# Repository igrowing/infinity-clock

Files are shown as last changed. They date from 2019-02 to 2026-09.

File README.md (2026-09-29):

# Infinity Mirror Clock

This repo follows and inspired by http://barkengmad.com/rise-and-shine-led-clock/

Original Morgan Barke's video:
[See the magic](https://youtu.be/YErWfe0aTiQ "Yoohoo!")

I like the original inifinity clock after reviewing dosen (or even more) similar devices. I appreciate Morgan's creativity and generosity for making his project public. Sharing is caring, and I'm giving back :)

This project fixes few issues in original clock and improves usability, user experience, and build ease.

[The clock demo in all modes (1 min 18 sec)](https://www.youtube.com/watch?v=9rUNe92n67c)

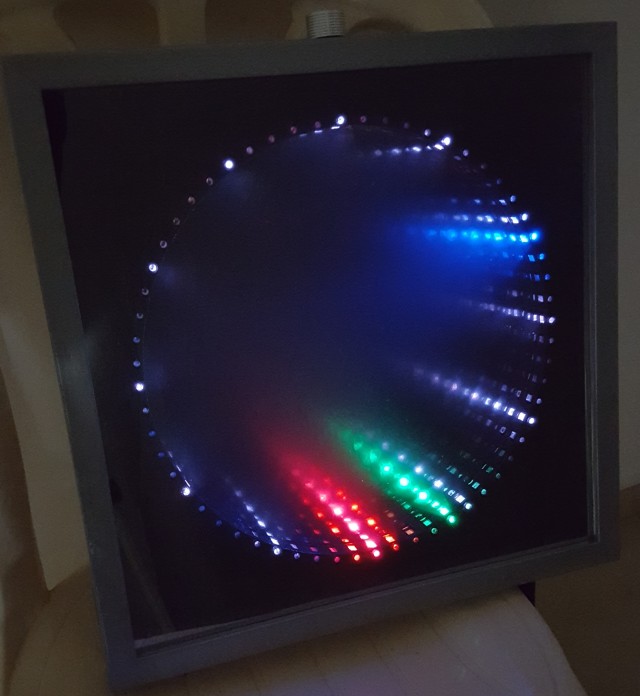
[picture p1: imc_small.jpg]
Infiniti mirror clock


# Features
- 8 modes of _clock_ display.
- 3 modes of _alarm_ display.
- Minute discrete timer.
- Demo mode.
- Buzzer.
- Power independent time count and settings store.
- WOW effect :)

# Usage
[See the PDF chart.](Infinity%20mirror%20clock%20user%20guide.pdf)

For fans of video guides:
- [Choosing Display mode of clock](https://www.youtube.com/watch?v=vU_UOzZHfpM)
- [Setting time and upright position](https://www.youtube.com/watch?v=-KVNCHQzmkM)
- [Alarm usage](https://www.youtube.com/watch?v=D5s8VyNlAFA)
- [Timer usage](https://www.youtube.com/watch?v=lTOYV0bmhKc)
- [Jump to demo mode and back to clock](https://www.youtube.com/watch?v=sZ3GmazdSDI)
- [Full user guide in one video](https://www.youtube.com/watch?v=MvB9e6Ny7ps)

# Changes vs. original clock
- Clock can be rotated by 90 degrees. This is useful for displaying the clock with the knob on the top (like traditional stopwatch) or on the right side (like tratitional watch).
- Use RTC NVRAM instead of EEPROM: this saves EEPROM wear out.
- Added rainbow to demo, endless demo, exit from demo by click.
- Move rotary button from A3 to D4: this helps ease of assembly.
- Refactor menu button work. Less code, easy readable.
- Keep clock mode and restore it after power failure.
- Refactor and make stable the rotary encoder.
- Breathing clock is more distinctive.
- Buzzer in Alarm and Timer modes.
- Remove excessive Serial prints.
- New Starry night clock mode.
- About 25% less code lines.
- Numerous bugs fixed.

# Build/compile
## Software
Original clock comes with libraries in archive. The libraries are outdated. Install in your Arduino/Platformio environment following libraries _before_ compiling:
- FastLED v3.2.1 and up
- Bounce2
- RTCLib
- Encoder of Paul Stoffregen
- EasyBuzzer

Likely, following libs are preinstalled by default:
- Wire

> Important: For some reason, the PlatformIO couldn't pick the EasyBuzzer. I guess this is related to [known bug of PlatformIO](https://community.platformio.org/t/platformio-home-page-cant-open/2768). Since numerous attempts to fix it failed, I switched to [command line control of libraries and boards](https://docs.platformio.org/en/latest/userguide/lib/index.html). So far it worked well, except the EasyBuzzer. Therefore, I added it to this repo: it will be easier to compile the entire project.

## Mechanics
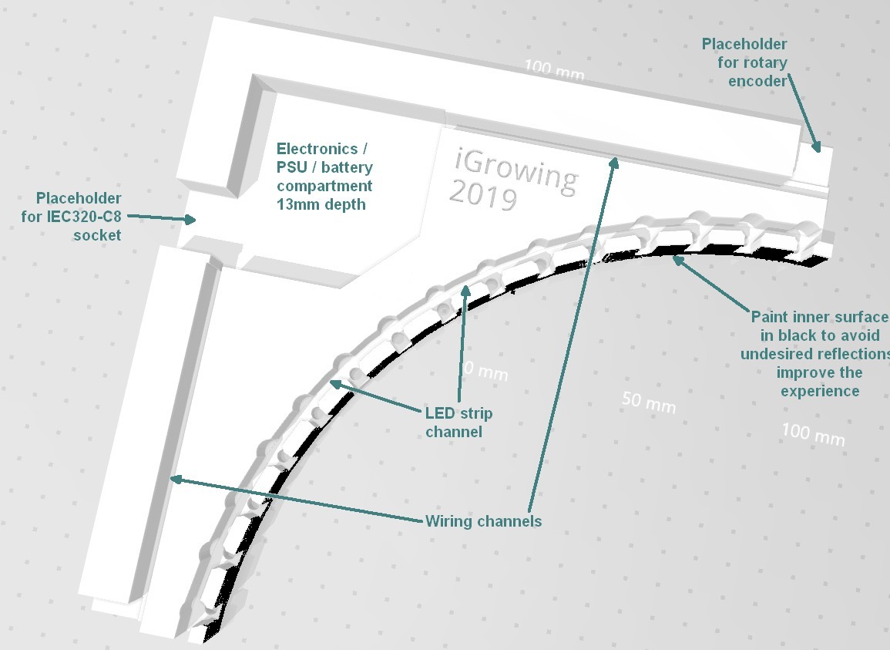
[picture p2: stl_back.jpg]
Back side of 3D model


Beside electronic components following material is needed:
- Knob for rotary encoder. 6mm inner diameter, the rest is on your taste. From 1.5 to 18 USD on eBay.
- Base plate made of layered wood or plastic for the back, 4-6mm thick, 38x38cm.
- PMMA or polycarbonate sheet for the front, 2.5-3mm thick, 38x38cm.
- Semi-transparent mirror, found on Amazon as "One Way Window Film". 
- Non-transparent mirror, found on Amazon.
- Frame on your taste from local painting shop.
- Wood or plastic for 3D model CNC milling. 16mm thick, 210x210mm (will be milled smaller). For CNC machine take 2-flute 20mm CEL carbide milling bits of 1/8".
or
- PETG or ABS filament for 3D printing, white color. PLA is good enough too, however, it's weak and thin part might break during handling/assembly.

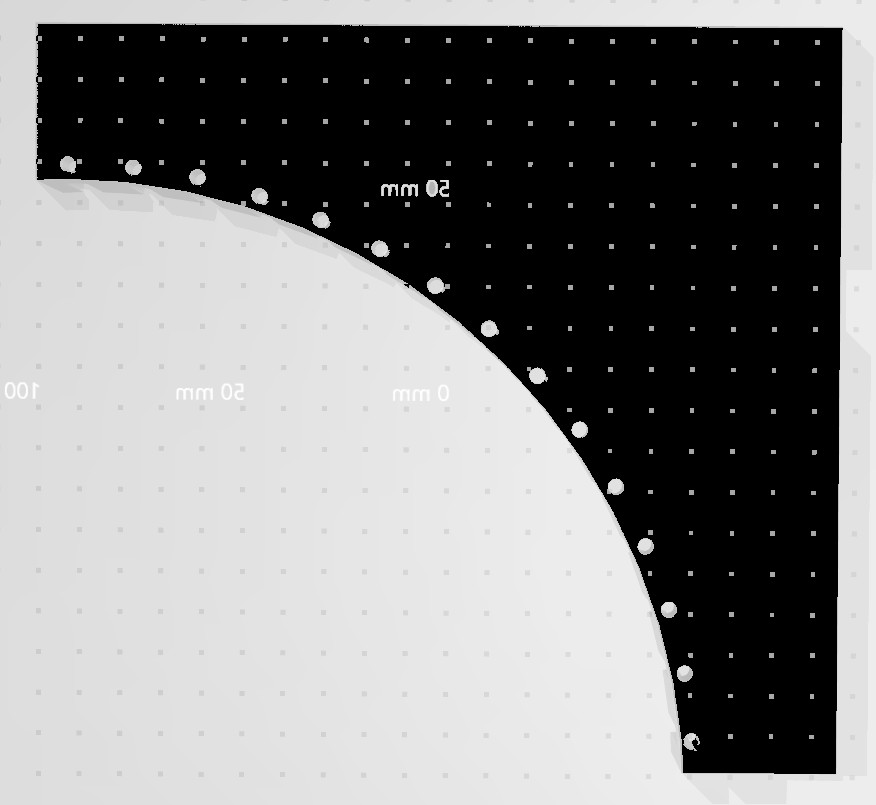
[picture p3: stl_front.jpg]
Front side of 3D model


It's hard to find large enough 3D printing service or CNC milling service. So I split the clock to 4 equal parts. Connect them side to side. Insert all electronics/wires in the channels. Place the back base with non-transparent mirror on all 4 parts connected. And screw all together.

Remember to paint the front side of the 3D model and inner ring with black. This stops unwanted reflections and improves the user experience (WOW effect). In the current STL model the light slots are high. This makes less distinguished mirror effect. Connecting free side of pins with 4 mm strip of black duct tape makes light windows, not channels and improves the UX.

## Electronics
The clock consumes about 1.5A @ 5V in worst case (white demo). Therefore, usual 2A USB charger is enough to power it up.

Per spare compartments: normally 1 compartment is populated with arduino electronics and the other one with PSU. In theory, 3 compartments can be used for 14400 Li-Ion or AAA Ni-MH batteries. Batteries might provide backup power up to 20 hours. I run my clock from AC mains.

Alternatives for power supply:
- Use rechargeable batteries.
- Use regular USB charger (2A or more).
- Hide the USB charger electonics in sepatate compartment and use IEC320-C8 socket for AC mains.

Lithium battery in RTC should be replaced once in few years. Rarely enough to make easy access to the electronics.

As LED strip, it's 1m 60 of WS8212B LEDs used. Any buzzer from old PC or Tablet or small loudspeaker is good.

# TODO
- Move alarm to RTC. This allows daily alarm.
- Buzzer sound isn't nice, kinda quack. Improve.
- Add PCB... (really?)

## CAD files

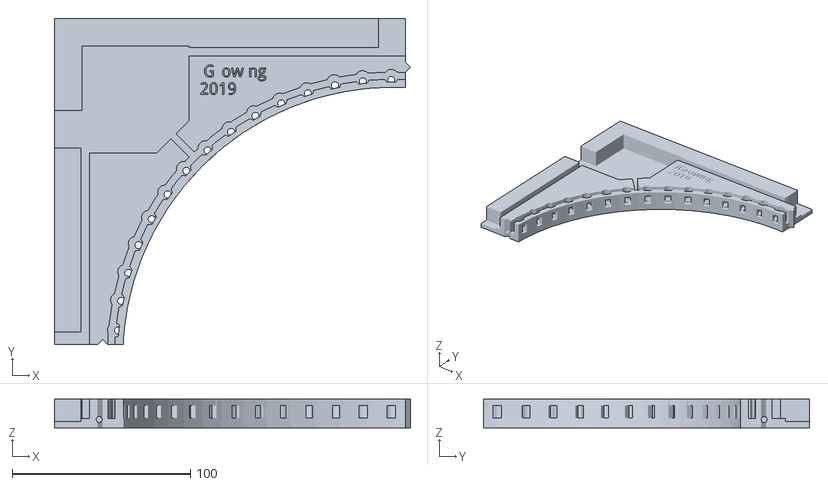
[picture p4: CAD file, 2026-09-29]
quarter clock wide opening.stl
199.8 x 183.0 x 16.0

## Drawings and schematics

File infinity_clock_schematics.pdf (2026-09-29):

A

A

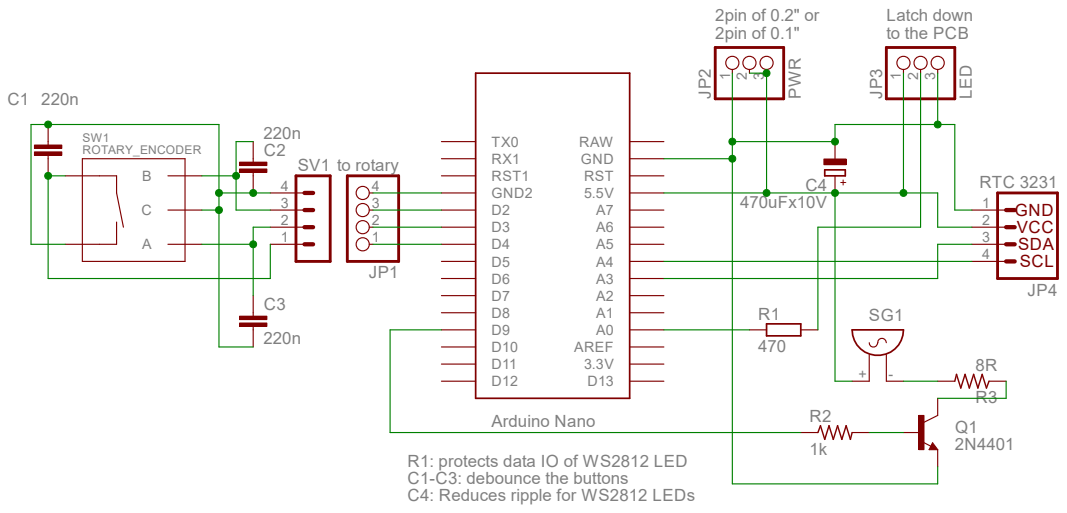
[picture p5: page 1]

ROTARY_ENCODER

R1: protects data IO of WS2812 LED
C1-C3: debounce the buttons
C4: Reduces ripple for WS2812 LEDs

29-Sep-26 17:00:17 C:\Users\igory\OneDrive\Documents\eagle\eagle\infinity mirror clock\clock.sch (Sheet: 1/1)

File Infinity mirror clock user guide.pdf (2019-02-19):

## Change mode +/-

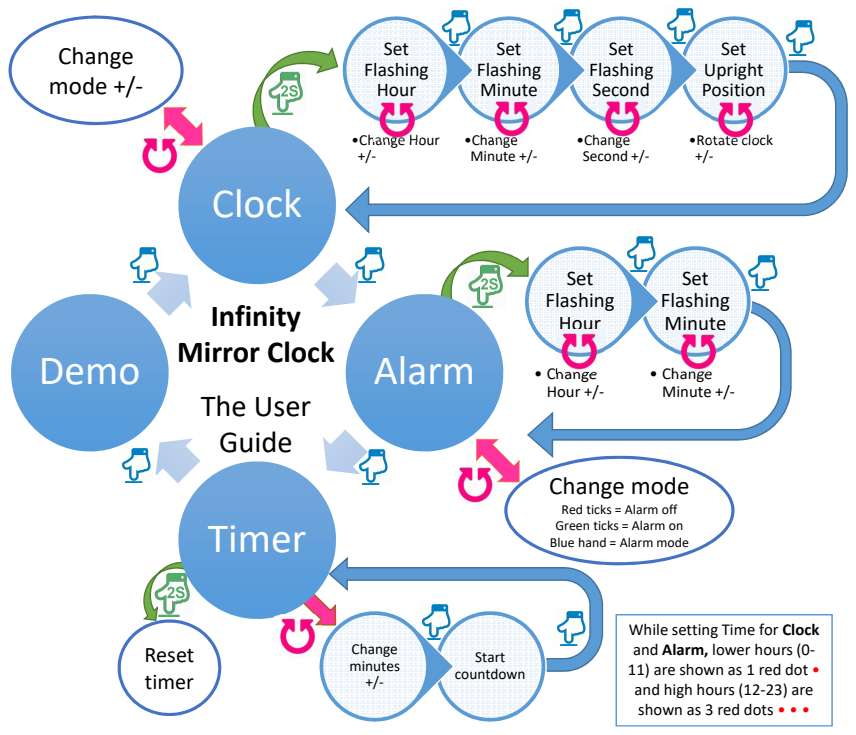
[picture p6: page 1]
Clock; Alarm; Timer; Demo; Set Upright Position; •Rotate clock +/-; Set Flashing Second; •Change Second +/-; Set Flashing Minute; •Change Minute +/-; Set Flashing Hour; •Change Hour +/-; • Change Minute +/-; • Change Hour +/-; Start countdown; Change minutes +/-; Change mode; Reset timer; Infinity Mirror Clock; The User Guide

Red ticks = Alarm off
Green ticks = Alarm on
Blue hand = Alarm mode

While setting Time for Clock
and Alarm, lower hours (0-
11) are shown as 1 red dot •
and high hours (12-23) are
shown as 3 red dots • • •

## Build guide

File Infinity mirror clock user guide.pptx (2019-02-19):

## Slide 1

Change mode +/-

Set Flashing Hour

  - Change Hour +/-

Set Flashing Minute

  - Change Minute +/-

Set Flashing Second

  - Change Second +/-

Set Upright Position

  - Rotate clock +/-

Set Flashing Hour

  - Change Hour +/-

Set Flashing Minute

  - Change Minute +/-

Change mode
Red ticks = Alarm off
Green ticks = Alarm on
Blue hand = Alarm mode

While setting Time for Clock and Alarm, lower hours (0-11) are shown as 1 red dot • and high hours (12-23) are shown as 3 red dots • • •

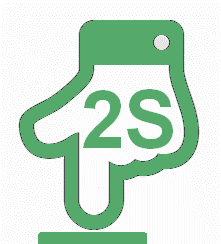
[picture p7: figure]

Clock

Demo

Alarm

Timer

Infinity Mirror Clock
The User Guide

Reset timer

Change minutes +/-

Start countdown

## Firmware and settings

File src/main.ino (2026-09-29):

/***********************************************************
 * Inspired by http://barkengmad.com/rise-and-shine-led-clock/
 * and based Morgan Barke's code.
 *
 * Modded by iGrowing 2019.
 * https://github.com/igrowing/infinity-clock
 *
 * Layout of the code:
 *   main.ino    setup, loop and the glue between the buttons, the menu and the hardware
 *   leds        the LED ring and the drawing primitives
 *   faces       the different ways of showing the time
 *   screens     setting screens, timer, demo and the alarm effects
 *   buzzer      the sound
 *   settings    what is kept in the NVRAM of the RTC
 *   lib/clock_logic   pure logic, unit-tested on the PC: menu state machine, beep timing, alarm decision, ...
 ***********************************************************/

//Add the following libraries to the respective folder for you operating system. See http://arduino.cc/en/Guide/Environment
#include <FastLED.h> // FastSPI Library version 3.1.X from https://github.com/FastLED/FastLED. Version 3.0.X has a bug: all LEDs are green by default.
#include <Wire.h> //This is to communicate via I2C. On arduino Uno & Nano use pins A4 for SDA (yellow/orange) and A5 for SCL (green). For other boards ee http://arduino.cc/en/Reference/Wire
#include <RTClib.h>           // Include the RTClib library to enable communication with the real time clock.
#include <Bounce2.h>          // Include the Bounce library for de-bouncing issues with push buttons.
#include <Encoder.h>          // Include the Encoder library to read the out puts of the rotary encoders
#include <menu_machine.h>     // Menu state machine, unit-tested on PC
#include "config.h"
#include "log.h"
#include "rtc.h"
#include "leds.h"
#include "faces.h"
#include "screens.h"
#include "buzzer.h"
#include "settings.h"

RTC_DS1307 RTC;     // Establishes the chipset of the Real Time Clock
MenuModel menu;     // Everything the user can change: state, modes, alarm, timer
Encoder rotary1(PIN2, PIN3); // Setting up the Rotary Encoder
Bounce menuBouncer = Bounce(PIN_MENU,30); // Instantiate a Bounce object with a 30 millisecond debounce time for the menu button
unsigned long lastRotary = 0;

// Silence the buzzer, forget any ringing state and go back to the clock.
void clearBuzzer() {
  buzzerReset();
  menu.state = STATE_CLOCK;
  menu.countDown = false;
}

void printDateTime() {
  DateTime now = RTC.now();
  // Sanity check for stored time
  if (now.hour() > 23 || now.minute() > 59 || now.second() > 59 || now.month() > 12 || now.day() > 31) {
    RTC.adjust(DateTime(2018, 1, 1, 1, 1, 1));
    now = RTC.now();
    Serial.println(F("Fixed date and time."));
  }
  printValue(F("Hour time is... "), now.hour());
  printValue(F("Min time is... "), now.minute());
  printValue(F("Sec time is... "), now.second());
  printValue(F("Year is... "), now.year());
  printValue(F("Month is... "), now.month());
  printValue(F("Day is... "), now.day());
}

void setup() {
  // Attach after enabling the pull-up: the global Bounce object was constructed before this and latched a floating pin level.
  menuBouncer.attach(PIN_MENU, INPUT_PULLUP);  // Uses the internal 20k pull up resistor. Pre Arduino_v.1.0.1 need to be "digitalWrite(PIN_MENU,HIGH);pinMode(PIN_MENU,INPUT);"

  // Start LEDs
  LEDS.addLeds<WS2812B, PIN_LEDS, GRB>(leds, NUM_LEDS); // Structure of the LED data. I have changed to from rgb to grb, as using an alternative LED strip. Test & change these if you're getting different colours.

  // Start RTC
  Wire.begin(); // Starts the Wire library allows I2C communication to the Real Time Clock
  RTC.begin(); // Starts communications to the RTC

  Serial.begin(9600); // Starts the serial communications

  // Load any saved setting since power off, such as mode & alarm time
  loadSettings(menu);
  setLedOffset(menu.ledOffset);
  rotary1.write(0);  // Set non-interrupt mode to rotary
  menu.state = STATE_CLOCK;

  printSettings(menu);
  printDateTime();

  buzzerBegin();
}

// Carry out what the menu state machine asked for.
void applyMenuEffects(const MenuEffects& fx) {
  if (fx.blinkDisplay) {  // blink display while button is pressed to indicate "entered adjust mode"
    clearLEDs();
    LEDS.show();
    delay(100);
  }
  if (fx.setTime) {
    RTC.adjust(DateTime(fx.newTime.year, fx.newTime.month, fx.newTime.day, fx.newTime.hour, fx.newTime.minute, fx.newTime.second));
  }
  if (fx.clearBuzzer) clearBuzzer();
  if (fx.stopBuzzer) buzzerStop();
  if (fx.resetSecTimer) restartSecondTimer();
  if (fx.resetSweep) resetSweep();
  if (fx.startDemo) startDemo();
  if (fx.saveLedOffset) setLedOffset(menu.ledOffset);
  saveSettings(menu, fx);
  if (fx.printDateTime) printDateTime();
  if (fx.waitAfterAlarmCancel) delay(300);  // let time for the button to be released
}

// Feed the state of the button into the menu state machine and act on the result.
void buttonCheck(Bounce& button, DateTime now) {
  MenuInput in = {};
  in.pressed = !button.read();
  in.heldMs = in.pressed ? button.currentDuration() : 0;
  in.released = button.rose();
  in.clockModeCount = clockFaceCount();
  in.now = toNowInfo(now);

  State stateBefore = menu.state;
  MenuEffects fx = menuStep(menu, in);
  applyMenuEffects(fx);

  if (stateBefore == STATE_ALARM && !fx.waitAfterAlarmCancel) {
    printValue(F("alarmSet is "), menu.alarmSet);
    printValue(F("alarmMode is "), menu.alarmMode);
  }
  if (!fx.waitAfterAlarmCancel) {
    printValue(F("Mode is "), menu.clockMode);
    printValue(F("State is "), (int)menu.state);
  }
}

void loop() {
  DateTime now = RTC.now(); // Fetches the time from RTC
  if (buzzerUpdate()) clearBuzzer();  // The timer beeps are over

  // Check for any button presses and action accordingly
  bool buttonChanged = menuBouncer.update();  // Update the debouncer for the menu button
  int rotaryPos = rotary1.read(); // Checks the rotary position
  if (rotaryPos != 0) {
    if (millis() - lastRotary >= ROTARY_SET_TIME_MS) {
      menu.rotaryMove = (rotaryPos < 0)?-1:1;  // Limit moves to single step.
      lastRotary = millis();
    }
    rotary1.write(0);  // Reset position, whether the move was valid or not.
  }
  if (buttonChanged || menu.rotaryMove != 0 || menu.countTime) {buttonCheck(menuBouncer, now);}

  clearLEDs();  // Not memset(leds, ...): it is ambiguous with FastLED 3.10+

  // Check alarm and trigger if the time matches
  switch (alarmPhase(menu, toNowInfo(now))) {
    case ALARM_DUE:
      menu.alarmTrig = true;
      alarmStarted();
      break;
    case ALARM_RINGING:
      alarmDisplay(menu.alarmMode);
      break;
    case ALARM_IDLE:
      break;
  }

  // Check the Countdown Timer
  if (menu.countDown) {
    menu.currentCountDown = countdownRemaining(menu.countDownTime, menu.startCountDown, now.unixtime());
    if (menu.currentCountDown <= 0) menu.state = STATE_COUNTDOWN;
  }

  // Set the LEDs of the current screen
  if (!renderScreen(menu, now)) menu.clockMode = RTC.readnvram(CLOCK_MODE_ADDR);  // Invalid face: restore the saved one.

  // Update LEDs
  LEDS.show();
}

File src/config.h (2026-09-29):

// Pins, timing constants and NVRAM layout of the clock.
#pragma once
#include <Arduino.h>
#include <clock_logic.h>   // NUM_LEDS, LED_OFFSET_L/R, HOLD_TIME_MS, ...

#define BEEP_TONE   700    // Hz
#define PIN_BUZZER  9      // OC1A (Timer1 hardware output). Must be D9 for the hardware tone.
#define PIN_LEDS    A0
#define PIN_MENU    PIN4
#define ROTARY_SET_TIME_MS 300
#define TIME_INTERVAL 5        // ms between steps of the LED animations
#define BLINK_PERIOD_MS 300    // Flashing while a value is being set: half of it off, half on

// Where the settings live in the NVRAM of the RTC
#define CLOCK_MODE_ADDR  0
#define ALARM_MIN_ADDR   1
#define ALARM_HR_ADDR    2
#define ALARM_SET_ADDR   3
#define ALARM_MODE_ADDR  4
#define LED_OFFSET_ADDR  5

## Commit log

2019-01-04 initial working sketch
    with bugs
    [main.ino]
2019-01-05 Code cleanup, first stage
2019-01-05 Code cleanup, stage 2
2019-01-25 3D printable, CNC millable model
    Make 4 of those. Flat side is a face.
    [quarter clock wide opening.stl]
2019-01-25 Schematics added
2019-01-25 Replaced with schematics
2019-01-25 Bugfix: on left rotate from 0-hour position the clock jumped to 3PM
    [main.ino]
2019-01-26 Added: buzzer, clock rotation by 90deg. Bugfixes. Code efficiency improved.
    [main.ino]
2019-01-26 STL graphics added
2019-02-08 Add notch/slit to STL, change wiring route
    [quarter clock wide opening.stl]
2019-02-13 Bugfix: don't trigger alarm while setting
    [main.ino]
2019-02-17 Bugfix: negative rotary move screwed up the clock and alarm modes
    [main.ino]
2019-02-20 Added 3D fit features
    [quarter clock wide opening.stl]
2019-02-22 Updated schematics
2019-02-26 Bug fix in demo mode + code optimization
    [main.ino]
2019-02-26 bug fix in DEMO_COLORS
    [main.ino]
2019-02-28 Code optimization + timer bugfix
    [main.ino]
2019-02-28 Bug fix in entering to timer after demo
    [main.ino]
2019-03-14 Added bridges to 3D STL: visual enhancement
    [quarter clock wide opening.stl]
2026-09-29 Move buzzer from A1 to D9 with use Timer1 for clean sound
    [main.ino]
2026-09-29 Add unit tests and fix 2 bugs
    [main.ino]
2026-09-29 Hardware buzzer, unit tests, bugfixes
    [main.ino]
2026-09-29 Fix intermittent entering into alarm mode on boot
    [main.ino]
2026-09-29 Partial code refactoring, minor bug fix with alarmFade
    [main.ino]
2026-09-29 Extract buzzer sequencer into separate lib
    [main.ino]
2026-09-29 Fix shifted pendulum animation
    [main.ino]
2026-09-29 Replace repeating code with functions
    [main.ino]
2026-09-29 Update schematics
